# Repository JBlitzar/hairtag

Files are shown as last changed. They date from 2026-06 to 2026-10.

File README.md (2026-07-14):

# hairtag



homemade airtag that's genuinely pretty good

 - ESP32C3 chip, openhaystack firmware (more FOSS than Apple, no crazy custom die)
 - 22mm diameter board (smaller than Apple's 33, although technically the product is taller overall)
 - Probably costs less than Apple (legit like $2 per board after paying the $40 flat setup fees)
    - (but if cost was really what you were hoping for, buy an aliexpress knockoff)
 - Comparable battery life to apple! (~229 days theoretically)
    - Actually configurable depending on what temporal accuracy you need and which ma consumption figure you believe: https://www.desmos.com/calculator/mcncridlhq
 - Designed in California (just like apple lol)

 ## Why I made this project

 I thought airtags were pretty cool. A while ago I was scrolling Github and I came across [openhaystack](https://github.com/seemoo-lab/openhaystack) (btw Seemoo lab has done all sorts of cool things that I've used before, shoutout to nexmon and opendrop). 

 Anyways, I figured I could make my own. It's good experience, because you basically get all the components of a devboard, plus power budgeting, and interesting firmware. Plus, I already own 10000 devboards but I own zero airtags so this is a product that I'd actually use and want. A project that has both cool value and educational value gives you so much more motivation than one that only has the latter. 

## Schematic



## PCB



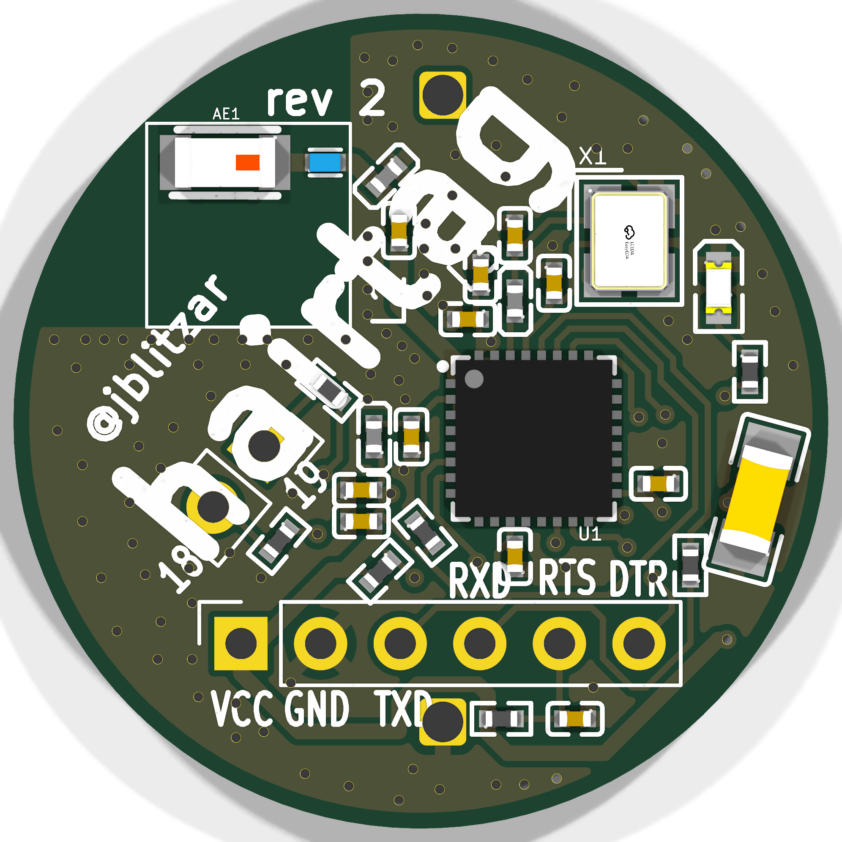
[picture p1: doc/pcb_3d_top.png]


## Wiring diagram for flashing

The standard way is a CP2102 USB-UART dongle wired straight to the flashing header (VCC, GND, TXD, RXD, EN, DTR):

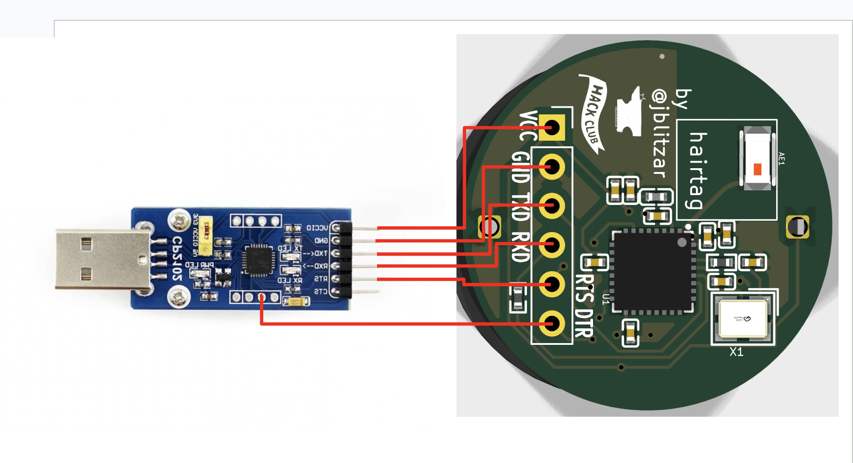
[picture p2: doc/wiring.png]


Alternatively, if you have an [Icepi Zero](https://www.crowdsupply.com/icy-electronics/icepi-zero) FPGA, you can use its onboard USB-UART bridge as the flasher. See [`software/fpga/`](software/fpga/).

## Gallery

https://github.com/user-attachments/assets/a9827342-8f9d-4dc0-8821-d6cf14613d8d

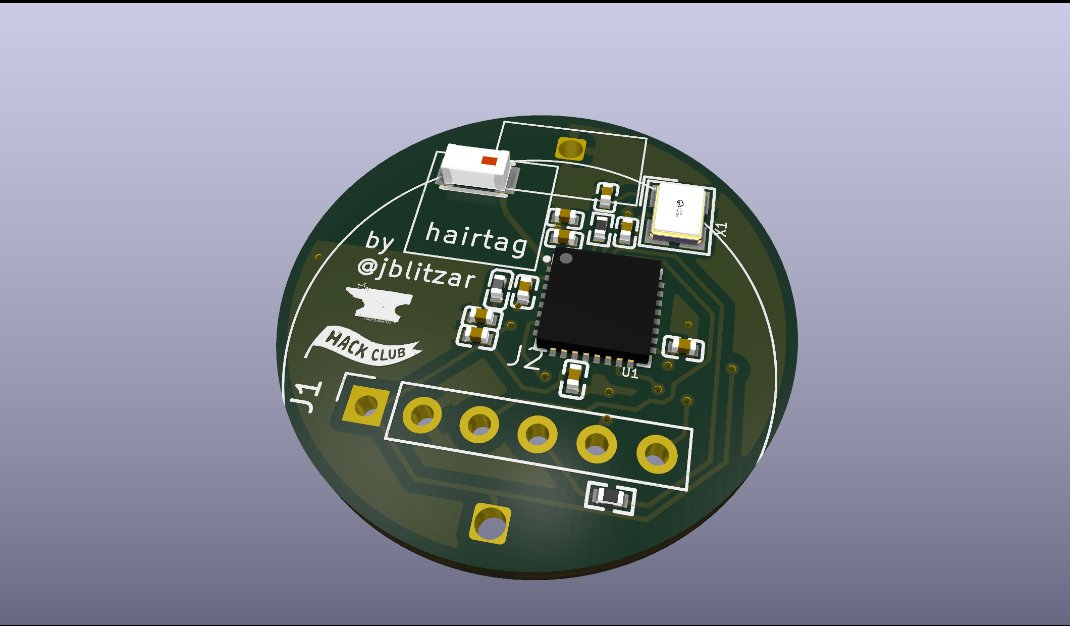
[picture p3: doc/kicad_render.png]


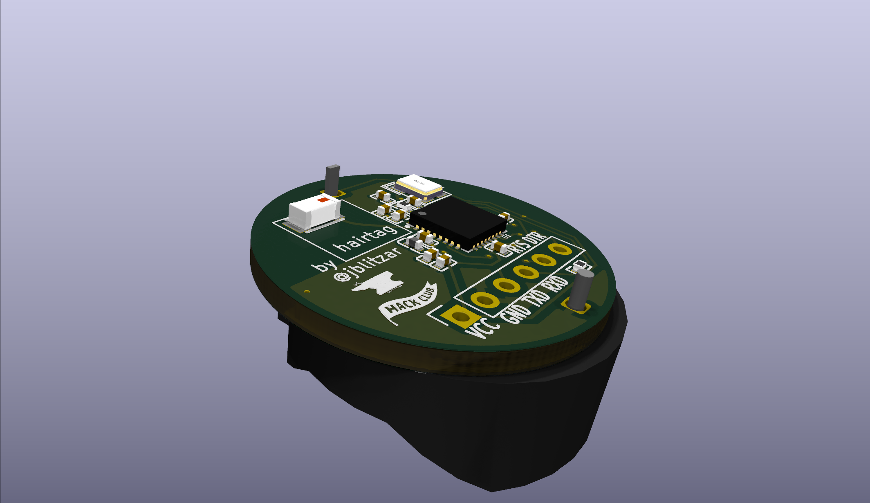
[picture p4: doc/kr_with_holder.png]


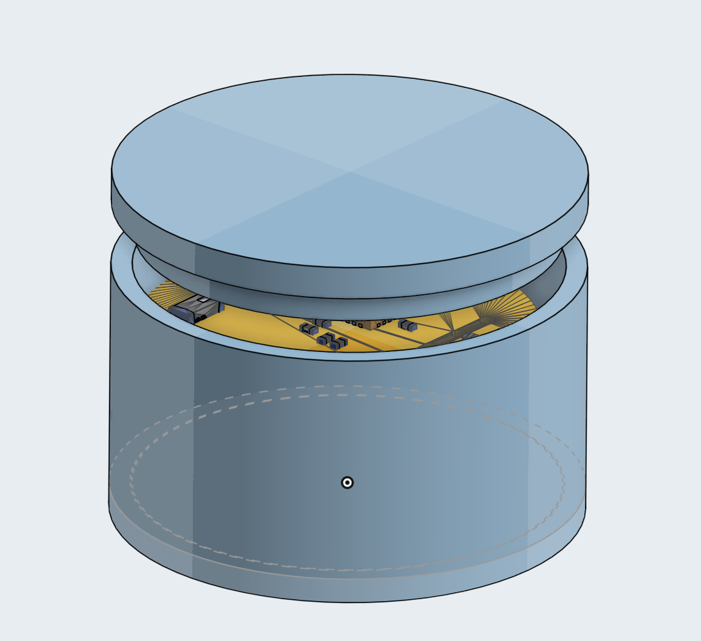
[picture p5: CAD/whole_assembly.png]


## Usage instructions

See [`software/README.md`](software/README.md). It's quite involved.

## Bom

|Item |Link |Cost |Notes |Running Total|
|---|---|-----|---|---|
|CP2102 for flashing |http://waveshare.com/cp2102-usb-uart-board-type-a.htm |4.99 |This one has a specific pinout that's useful, also waveshare's more reputable |4.99 |
|PCB + PCBA + JLC shipping|N/A |42.02|Cost for 2x pcba. I'm willing to pay $4 extra out of pocket to get the 5x PCBA |47.01 |
|CR2032 batteries |https://www.aliexpress.us/item/3256808176964698.html |0 |self-sourced, alt amazon link: https://www.amazon.com/Energizer-2032-Battery-CR2032-Lithium/dp/B0042A9UXC?th=1 |47.01 |
|battery holder |https://www.amazon.com/RuiLing-CR2032-Button-Battery-Holder/dp/B07PNK5D6H|6.69 |it's actually cheaper than what I could find on aliexpress (at least that had the footprint that I wanted and free shipping)|53.7 |
|Shipping / taxes |N/A |11 |TBD, from all the other ones not counting pcba |64.7 |
|Case (printed) |N/A |0 |self-sourced, alternatively print legion is also free |64.7 |

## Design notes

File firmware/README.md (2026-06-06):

# Firmware

This directory contains everything needed to turn an ESP32-C3 into an Apple Find My tracker and query its location from your machine.

Think of it this way: I basically got five half-broken implementations off of github, all at least two years old, tried things until it worked, and merged them together into one cursed readme here.

This was one of the hardest installation processes I've ever documented (or done), probably superseded in difficulty only to that one arm64 rabbit r1 rooting project.

This will likely only work on a mac, because apple is apple.

For the sake of reproducibility, here's what to do:

## How it works

1. `esp32c3-openhaystack/` runs on the ESP32-C3 and broadcasts BLE advertisements that Apple devices interpret as a Find My accessory.
2. `findmy/` runs on your computer, authenticates with Apple, and fetches/decrypts location reports from the Find My network.

## Prerequisites

- macOS (special apple things)
- [Docker Desktop](https://www.docker.com/products/docker-desktop/) running
- [uv](https://docs.astral.sh/uv/) package manager
- An Apple ID with SMS 2FA enabled
- The flashing setup as described in [README.md](/README.md#wiring-diagram-for-flashing)

## Anisette server

```bash
docker network create mh-network
docker run -d --restart always --name anisette -p 6969:6969 \
  --volume anisette-v3_data:/home/Alcoholic/.config/anisette-v3 \
  --network mh-network \
  dadoum/anisette-v3-server
```

Verify it's running:

```bash
curl http://localhost:6969
```

## Generate keys

See instructions in the esp32c3 README: [`esp32c3-openhaystack/README.md`](esp32c3-openhaystack/README.md)

```bash
cd esp32c3-openhaystack/
uv sync
uv run scripts/keygen.py
```

This creates a `.keys` file (e.g. `XXXXX.keys`) in the `scripts/output/` directory containing your private key, advertisement key, and hashed advertisement key. Copy the .keys file to `findmy`.

## Flash the firmware

Follow the instructions in [`esp32c3-openhaystack/README.md`](esp32c3-openhaystack/README.md). In short:

```bash
cd esp32c3-openhaystack/
# Build and flash firmware
pio run -t upload
# Write your keys to the device (copy your .keys file to scripts/input/ first)
python3 scripts/keywriter.py
```

After flashing and resetting, the device starts advertising immediately.

## Create the reports database

```bash
cd findmy/
sqlite3 reports.db 'CREATE TABLE reports (id_short TEXT, timestamp INTEGER, datePublished INTEGER, payload TEXT, id TEXT, statusCode INTEGER, PRIMARY KEY(id_short,timestamp))'
```

## Authenticate with Apple

Disclaimer: I'm not responsible if something happens to your apple account. Prefer an alt account.

My personal advice is that it's probably fine though.

```bash
cd findmy/
uv run request_reports.py --regen
```

You'll be prompted for your Apple ID, password, and a 2FA code.

Now, you won't actually get a 2fa code texted to you. For that, go to icloud.com, sign in, it will give send an approval code to your phone. But don't use that either. You click, "can't use this device" or whatever, then select the option to send an *SMS* code via text. Then paste that sms code (not the initial approval code) into the terminal (not icloud.com)

On success, the script saves `auth.json` in the `findmy/` directory. Subsequent runs reuse it without prompting.

## Query locations

```bash
cd findmy/
./locate.sh
```

Output looks like:

```
200: 8 reports received.
8 reports used.

{'lat': 33.6104, 'lon': -153.3900, 'conf': 1, 'status': 0, 'timestamp': 1749234567, 'isodatetime': '2026-06-06T14:42:47', 'key': 'XXXXX', 'goog': 'https://maps.google.com/maps?q=33.6104,-153.3900'}
found:   ['XXXXX']
missing: []
```

The `goog` URL opens the location in Google Maps.

a TODO for the future is to make this a nice TUI. 

### Options

| Flag | Default | Description |
|---|---|---|
| `--hours` | 24 | Look back this many hours for reports |
| `--regen` | off | Force re-authentication (needed when token expires) |
| `--prefix` | (none) | Only query `.keys` files starting with this prefix |
| `--trusteddevice` | off | Use trusted device 2FA instead of SMS |

## Auth token expiry

idk, sometimes it expires.

```bash
uv run request_reports.py --regen
```

The anisette Docker container must be running for this to work.

## On apple IDs

You could make a burner apple id if you want I guess, it's kind of a pain though, what with the android apple music bypass and whatnot.

## Licensing

I did not write this myself. I copied these two repositories, patched them so that they worked, and put them together.

Thank you, @biemster, @timbeh, and of course seemoo lab. 

https://github.com/biemster/FindMy

https://github.com/timbeh/esp32c3-openhaystack

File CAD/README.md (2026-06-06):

## Cad

Onshape link: https://cad.onshape.com/documents/0e94dcea26cc064076fa7957/w/f8a446f4ff724744298d30b3/e/f3de4cc3b830680613227711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

Exported STEPs also available in this directory.

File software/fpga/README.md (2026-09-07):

# Icepi Zero FPGA flasher

This is how I'm going to personally flash since I want to avoid spending 16 dollars. 

You only need this if you happen to have an Icepi Zero lying around. For
everyone else, the CP2102 dongle in the main
[wiring diagram](/README.md#wiring-diagram-for-flashing) is simpler.

## How it works

[`top.sv`](top.sv) is a pure combinational pass-through. esptool talks to the
Icepi's onboard FTDI exactly as it would to a CP2102; the FPGA just forwards
the data and modem-control lines (RTS->EN, DTR->boot) to four GPIOs:

| FTDI signal | FPGA pass-through | Hairtag pin |
|---|---|---|
| TXD (`usb_rx`) | `flash_txd` | TXD (ESP U0RXD) |
| RXD (`usb_tx`) | `flash_rxd` | RXD (ESP U0TXD) |
| RTS# (`usb_rtsn`)| `flash_en`  | EN (CHIP_EN) |
| DTR# (`usb_dtrn`)| `flash_dtr` | DTR (GPIO9 boot)|

## Wiring

The four signal GPIOs sit on the odd-numbered outer row, so VCC/GND/signals
are all reachable along one side of the 40-pin header:

| Hairtag pin | Icepi 40-pin header | ECP5 site |
|---|---|---|
| VCC | pin 1 (3V3) | — (rail) |
| GND | pin 9 (GND) | — (rail) |
| TXD | pin 3  | T2 |
| RXD | pin 5  | R2 |
| EN  | pin 7  | R1 |
| DTR | pin 11 | R3 |



## Build and load

Requires the open-source ECP5 toolchain (`yosys`, `nextpnr-ecp5`, `ecppack`,
`openFPGALoader`).

```bash
make debug    # load to SRAM (lost on power cycle) - good for flashing sessions
make install  # write to flash (persists)
make clean
```

Once the bitstream is loaded, flash the hairtag the normal way (`pio run -t
upload`, `keywriter.py`, etc.) pointing esptool at the Icepi's serial port.

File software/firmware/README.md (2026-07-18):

# README copied from original repo. Not all this info is relevant. Also at this point the code has been heavily modified. 

See https://github.com/timbeh/esp32c3-openhaystack .

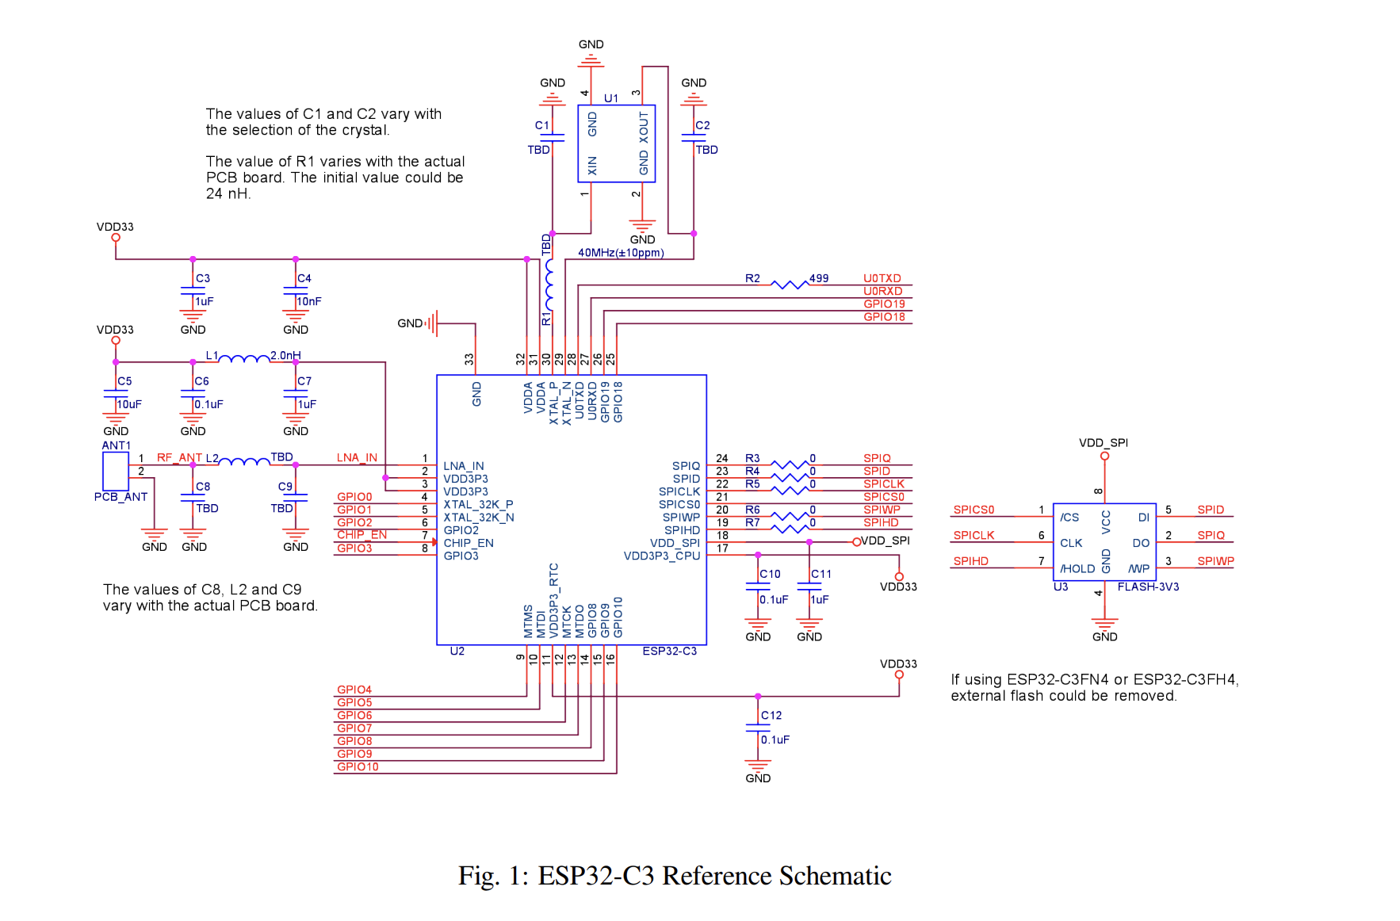
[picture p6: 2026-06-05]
doc/esp_ref_schematic.png

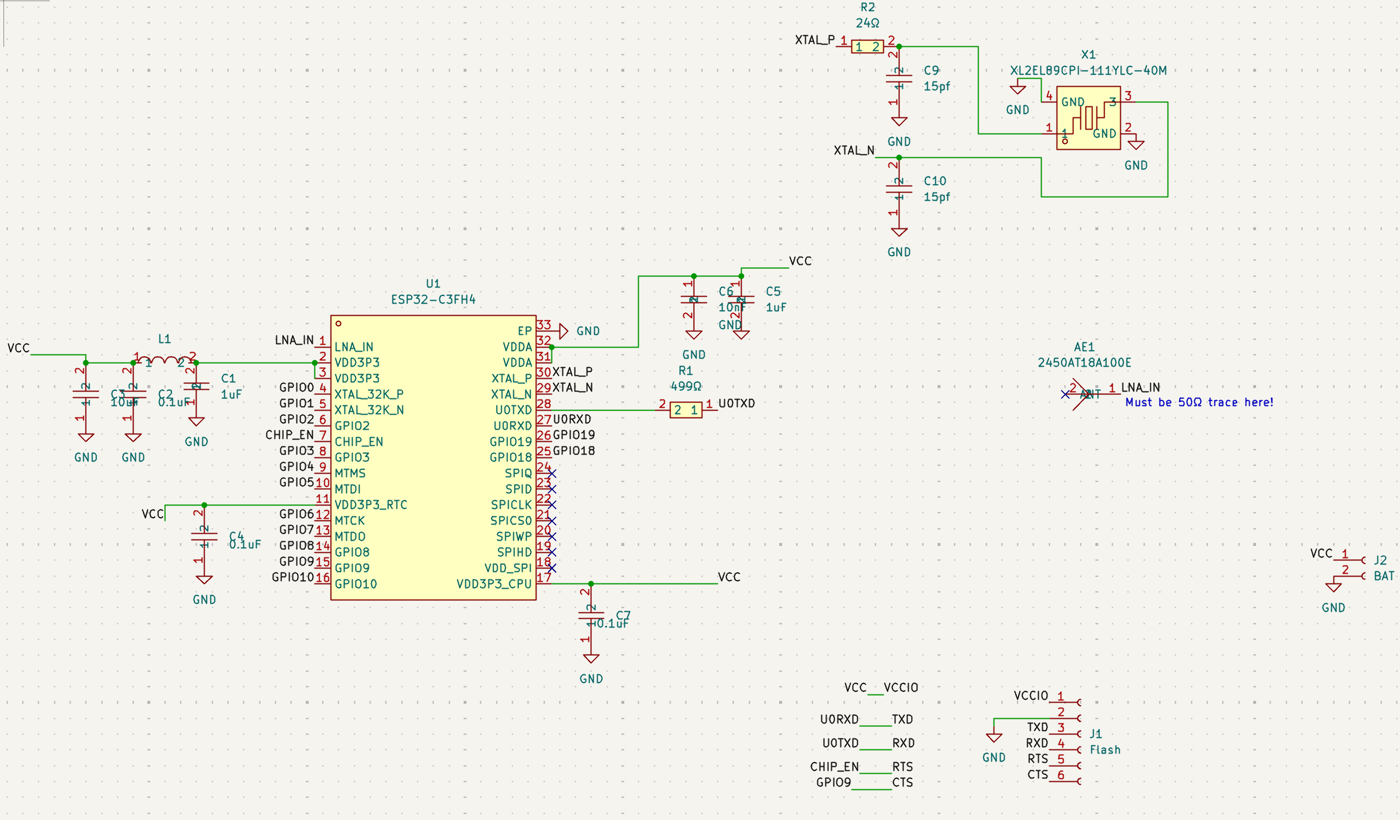
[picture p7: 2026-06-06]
doc/schematic.png

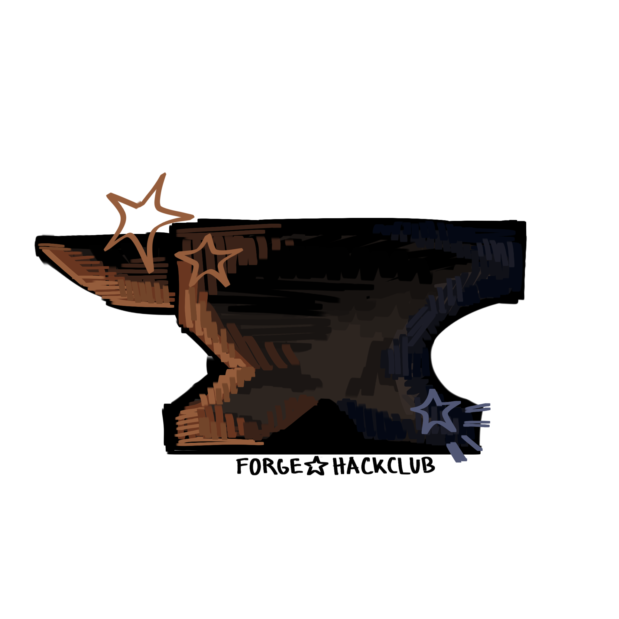
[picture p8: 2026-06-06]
doc/forge.png

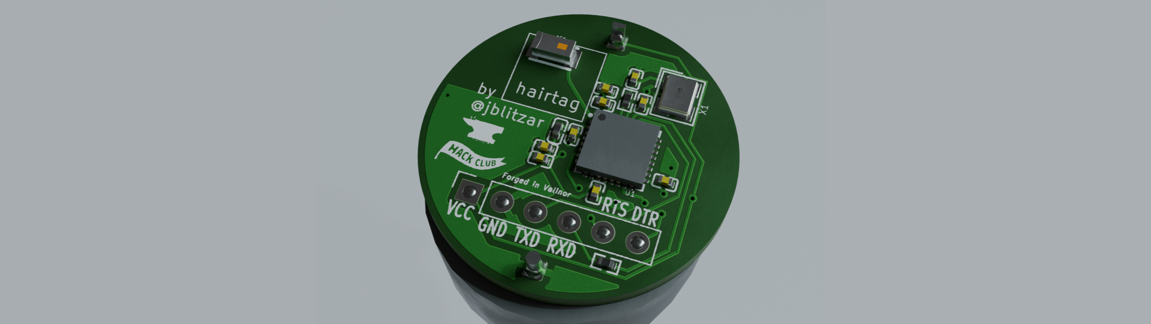
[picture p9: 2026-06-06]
CAD/render/br1_wide.png

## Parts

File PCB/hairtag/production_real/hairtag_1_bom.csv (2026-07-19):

Designator | Footprint | Quantity | Value | LCSC Part #
AE1 | ANT-SMD_L3.2-W1.6 | 1 | 2450AT18A100E | C89334
C1, C5, C8 | C0402 | 3 | 1uF | C52923
C10, C9 | C0402 | 2 | 15pf | C1548
C11 | C1206 | 1 | 100uF | C15008
C12 | C0402 | 1 | 1pF | C1550
C2, C4, C7 | C0402 | 3 | 0.1uF | C1525
C3 | C0402 | 1 | 10uF | C15525
C6 | C0402 | 1 | 10nF | C15195
L1 | L0402 | 1 | 2nH | C76769
L2 | L0402 | 1 | 15nH | C27143
L3 | L0402 | 1 | 2.7nH | C27123
L4 | IND-SMD_L1.0-W0.5-2 | 1 | 3.9nH | C98062
LED1 | LED0603-RD | 1 | FC-1608YXK-585F08 | C2286
R1 | R0402 | 1 | 499Ω | C2960788
R2, R7 | R0402 | 2 | 22 | C25092
R3 | R0402 | 1 | 0402WGF3300TCE | C25104
R4, R5, R6 | R0402 | 3 | 10k | C25744
U1 | QFN-32_L5.0-W5.0-P0.50-TL-EP3.7 | 1 | ESP32-C3FH4 | C2858491
X1 | CRYSTAL-SMD_4P-L3.2-W2.5-BL | 1 | XL2EL89CPI-111YLC-40M | C5444549

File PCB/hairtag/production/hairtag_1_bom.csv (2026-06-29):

Designator | Footprint | Quantity | Value | LCSC Part #
AE1 | ANT-SMD_L3.2-W1.6 | 1 | 2450AT18A100E | C89334
C1, C5 | C0402 | 2 | 1uF | C52923
C10, C9 | C0402 | 2 | 15pf | C1548
C11 | C1206 | 1 | 100uF | C15008
C2, C4, C7 | C0402 | 3 | 0.1uF | C1525
C3 | C0402 | 1 | 10uF | C15525
C6 | C0402 | 1 | 10nF | C15195
C8 | C0402 | 1 | 1uF | C29266
J1 | PinSocket_1x06_P2.54mm_Vertical | 1 | Flash
J2 | Untitled | 1 | BAT
L1 | L0402 | 1 | 2nF | C76769
L2 | L0402 | 1 | 15nH | C76769
LED1 | LED0603-RD | 1 | FC-1608YXK-585F08 | C89811
R1 | R0402 | 1 | 499Ω | C2960788
R2, R7 | R0402 | 2 | 22 | C105872
R3 | R0402 | 1 | 0402WGF3300TCE | C105872
R4, R5, R6 | R0402 | 3 | 10k | C105872
U1 | QFN-32_L5.0-W5.0-P0.50-TL-EP3.7 | 1 | ESP32-C3FH4 | C2858491
USB1 | PinSocket_1x02_P2.54mm_Vertical | 1 | USB
X1 | CRYSTAL-SMD_4P-L3.2-W2.5-BL | 1 | XL2EL89CPI-111YLC-40M | C5444549

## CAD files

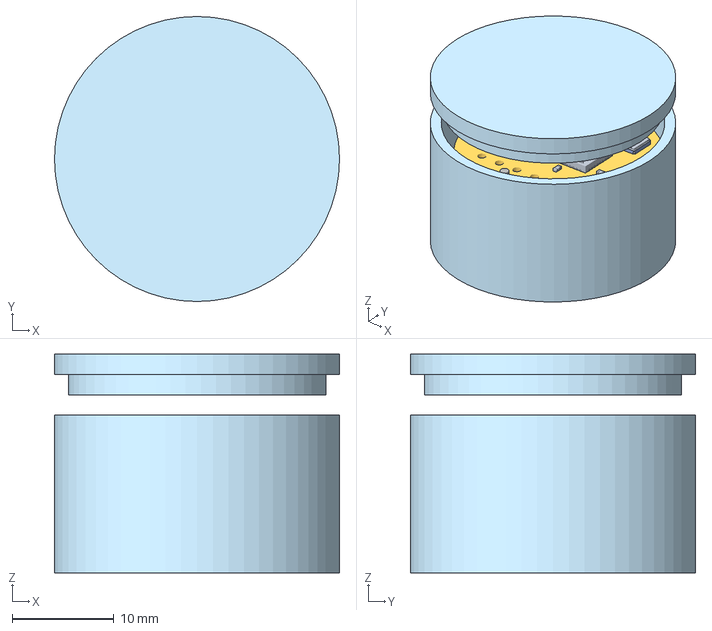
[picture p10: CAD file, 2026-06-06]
CAD/hairtag_whole_assembly.step
28.0 x 28.0 x 21.5 mm

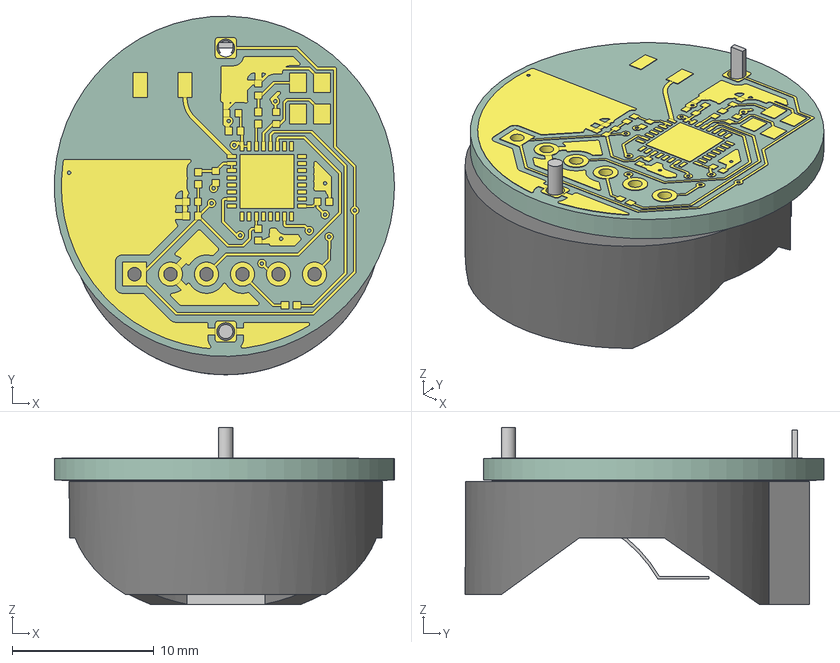
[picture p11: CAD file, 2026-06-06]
doc/hairtag_pcb_merged.step
24.0 x 25.3 x 12.5 mm
ť x 3
hairtag_copper
hairtag_PCB

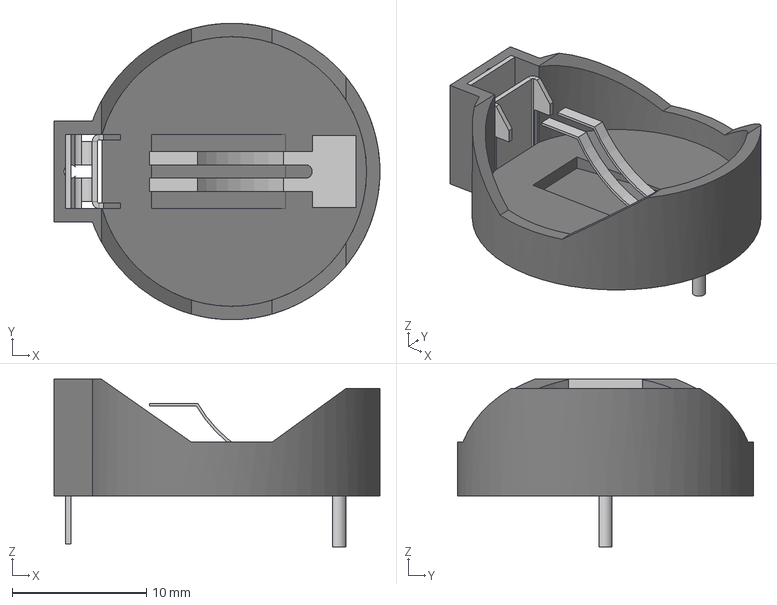
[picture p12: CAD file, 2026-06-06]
PCB/hairtag/battery_holder.stp
24.3 x 22.1 x 12.5 mm

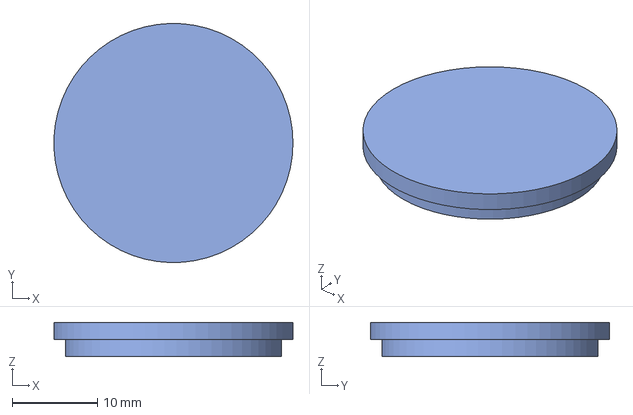
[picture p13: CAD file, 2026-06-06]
CAD/case_top.step
28.0 x 28.0 x 4.00 mm

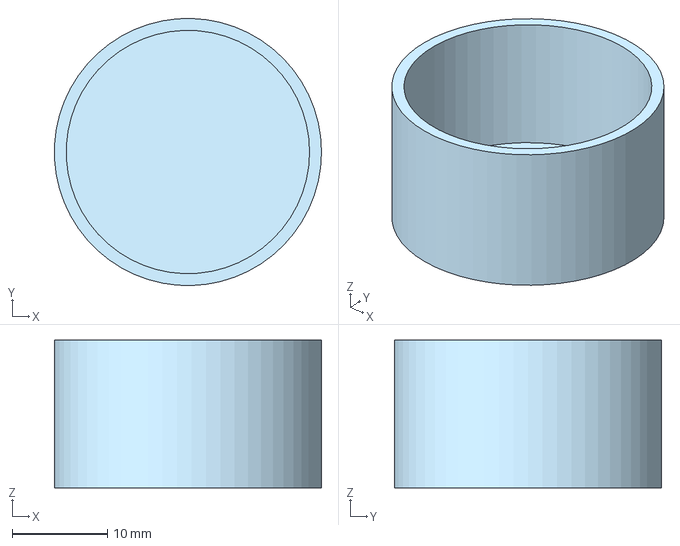
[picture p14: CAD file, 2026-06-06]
CAD/case_bottom.step
28.0 x 28.0 x 15.5 mm

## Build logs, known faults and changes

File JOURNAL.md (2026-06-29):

---
title: "hairtag"
author: "jblitzar"
description: "homemade airtag that's genuinely pretty good"
created_at: "2026-06-04"
---

# 6/4/2026 9 AM - Research and project idea

_Time spent: 1.5h_

Basically did some research and thinking about this project. I think it has the potential to be really cool. I sent my musings in slack to ask for feedback, but here's how it's feeling so far:

I think it'd be cool to make my own airtags. There exists openhaystack firmware to connect to apple's mesh, so this is feasible at least in theory, plus there already exist third party airtags so others have done it at least
In terms of complexity, I'd imagine it's at or above a devboard.
One hard part is going to be power mangement

In terms of capable chips, I see two options: the esp32 and the nrf. Both have openhaystack ports.

esps have ble soc, and I think the c3 is pretty stripped down and optimized. It draws maybe 150 ua, so about six months on an AAA battery, pretty good

There's also the nrf, which is more "professional grade" I guess. It has a harder toolchain, but draws much less current. Even on a tiny cr2032 coin battery, it'd last a really long time. I'm leaning towards the c3 though.

With regards to that, I also have the option of using the raw qfn chip or using the package. Both fit within spatial budget.

What I'm leaning towards now is esp32c3 qfn, off the shelf external antenna, AAA battery. It's not quite the professional form factor of the coin cell x nrf, but honestly it has some charm to it. qfn feels like just the right amount of challenge, and also I want pcba :wesh:



Alright, locking things in:

- MCU: esp32c3 qfn: https://www.lcsc.com/product-detail/C2858491.html
- Antenna: Molex 2450AT18A100E (datasheet: https://www.lcsc.com/datasheet/C89334.pdf)
- Power: battery tbd (probably AAA)
- Firmware: Openhaystack for esp32
- Flashing: expose tx,rx,gnd,boot,en plus CP2102

# 6/4/2026 4 PM - Schematic and Placement

_Time Spent: 3h_

Found a great datasheet on the esp32, https://docs.espressif.com/projects/esp-hardware-design-guidelines/en/latest/esp32c3/esp-hardware-design-guidelines-en-master-esp32c3.pdf

Absolute gold mine; It has a reference design.

Anyways, useful stuff for the future:

1uf: C52923
inductor: C76769 2nH
100nf: C1525
10uf: C15525
10nf: C15195
499Ω: C2960788
crystal: C5444549 (specify 10pf) (datasheet: https://www.lcsc.com/datasheet/C5444549.pdf)
15pf: C1548
24Ω: C270625

Here's what it looks like!



And the placement: 



I also researched firmware, I found this lovely implementation at https://github.com/timbeh/esp32c3-openhaystack/tree/main .
Now, if it advertises for just 20ms and then deep sleeps for the rest of the ten seconds, that consumes  = 0.03996 mA, so on a 220 mAh battery, that's 229 days of life!! This is pretty great, so we don't even need to worry about optimizing life. No nrf regrets.

So the coin cell is back on the table. So I just slightly redesigned the form factor. Honestly, this is pretty good to almost start routing.



Actually, update: I was able to fully fit the whole thing inside a 22mm circle.


Things to consider with routing:
 - Silly stuff with the impedance of the antenna (most annoying)
  - Double check this with the datasheet.
  - Also keep out zone
 - Caps, antenna, crystal should all be via-free, the rest is fair game (signal, ground, power)
  - What this likely means is that I should route these first. 

# 6/4/2026 9 PM - First pass on routing

_Time Spent: 0.5h_

Reasonably fast routing thanks to my immaculate placement lol, just a bit of nudging around.

DRC passes! Just had to connect all the gnd planes, no other issues

Impedence calculators said that I would need a 3mm (!!) thick trace for my ble, but the pitch on the qfn package is literally 0.5mm. According to the internet, at my type of application, honestly, impedence matching is not allat. It'll be a negligible difference, I'm not trying to squeeze every last db out of this, it just needs to transmit to the nearest phone. So I guess I'll be getting 109Ω impedance instead of the reccommended 50Ω.

Internet says: "A safe rule of thumb in digital and low-frequency design is that if your trace or wire is less than 1/10 of the signal's wavelength, transmission line effects don't matter. Reflections won't have time to interfere with the original signal." My wire is 6mm and ble is 2.4ghz, so that's like 120mm. So I am fine.

Picture: 



TODOs eventually:
 - add silkscreen art
 - add the rest of the docs to make it shipped. This means:
  - BOM fully figured out (this has items not in pcba like the batteries!)
  - nice readme
  - nice case
  - et al.

We'll see how pricing comes out.

# 6/5/2026 3 PM - Silkscreen, BOM, docs

_Time Spent: 2.5h_

BOM optimization: swapped 4 extended LCSC parts for basic equivalents to cut PCBA costs.

https://basicp.art/ is such a gem of a resource

- C29266 -> C52923
- C60474 -> C1525
- C315248 -> C15525
- C86285 -> C1548

I also fleshed out the sourcing for the rest of the parts. I could spend some more time looking at alternatives, but it's about as cheap as it's going to get. I have as many Basic parts as possible, I'll probably pay for battery holders out of pocket, and a cheaper CP2102 will save me only like $5.

So while I was looking at my battery holders, I realized that I don't actually have to solder any bodge wires, and that there exists one with a very slick PCB integration. So I designed up a footprint and put it in. 


See, those pins can actually go into tht pads. These folks did it:



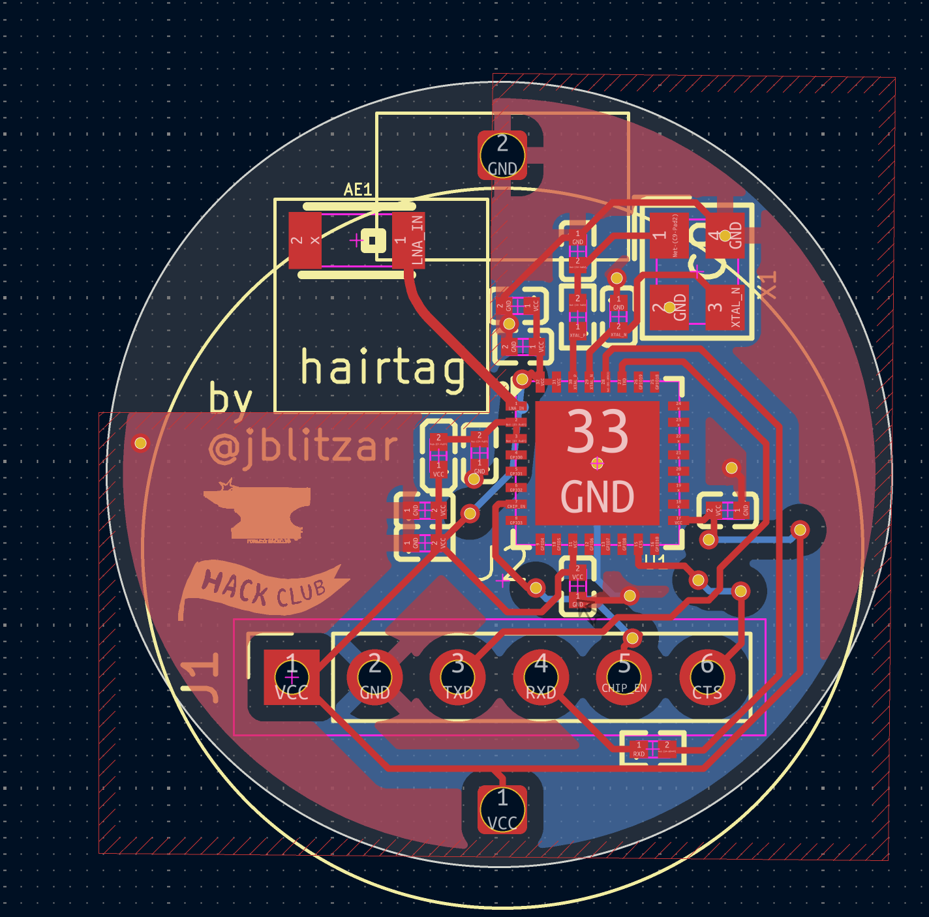
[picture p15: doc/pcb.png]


Alright, time to design a case.

I think a simple press fit will do. This is a ~25.5mm diameter circle, which accounts for the weird overlapping footprints. It'll be a weird fit, but it'll look cool on the outside

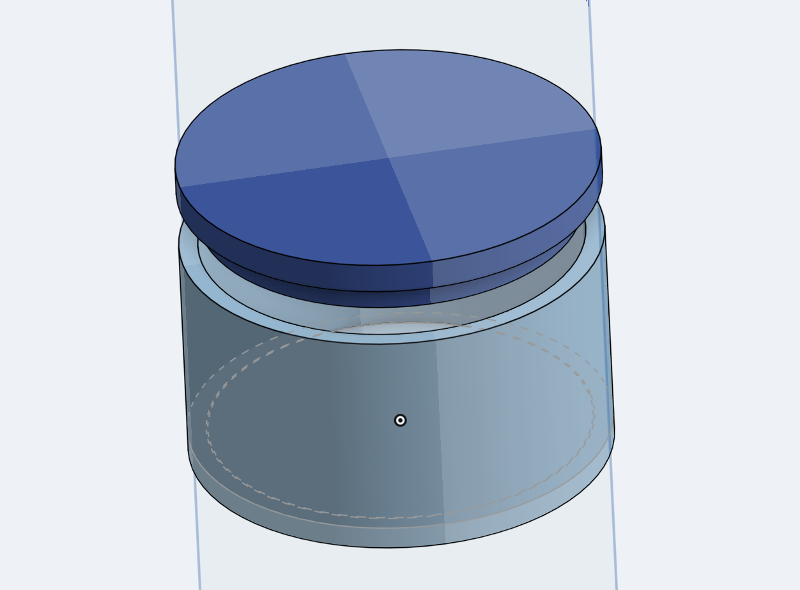
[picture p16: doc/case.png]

Next up, I wrote the README. For next session, I'll want to make a nicer render in blender, clean up the traces until they're *perfect*, and make sure that I all the proper documentation sorted here. (seems like I'll need a step file with my whole assembly)

# 6/6/2026 8 AM - README, Flashing pinout

_Time Spent: 2h_

*not counting time spent waiting for blender renders to render*

I was looking to bom optimize the flasher, but in the end, I need all the pins I'll use, because I need the RTS and DTR pins to autoboot. This is quite nice for qol. It'll be a sus bodge wire though.

Made the wiring diagram, made the composite PCB + case CAD and exported it into `CAD/`.

Next up, blender render!

Anyways, check the images in `doc/`.

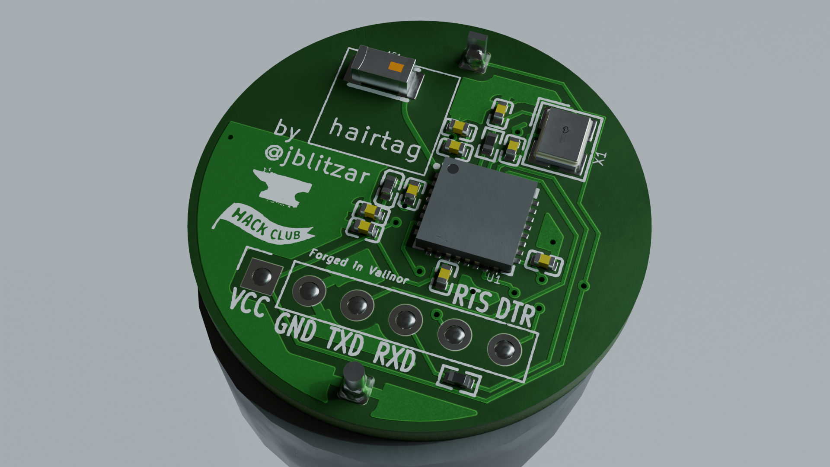
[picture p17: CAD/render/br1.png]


# 6/6/2026 1 PM - Fought demons to get firmware working

_Time Spent: 1.5h_

> at least.

**Hackatime project name**: `hairtag`, same as the repo

Doing this on a plain esp devboard because ofc parts have not arrived yet, should be the same I just edited platformio.

Basically it's everything in `firmware/`. Yeah, there were a lot of issues. I think I have tried five or six different openhaystack implementations, namely

- https://github.com/seemoo-lab/openhaystack (bad because requires sketchy legacy apple mail plugin that no longer works)
- https://github.com/timbeh/esp32c3-openhaystack (good, am using)
- https://github.com/dchristl/macless-haystack (Spent a long time on this one, auth doesnt work for whatever reason, cors errors on frontend)
- https://github.com/biemster/FindMy (Auth actually works, just a tui no frontend, tried using this auth with the macless frontend, didn't work)

My stack right now is `esp32c3-openhaystack` firmware (with the `fix-hint-byte` patch) and a patched FindMy.py that doesn't throw errors lol.
  - Update: findmy.py also had some logic bugs that I also patched regarding querying multiple keys

Anyways, I got real reports!! So ts actually works. I was so happy when I saw those jsons in stdout.

Let me expand on the journey a bit:
I spent way too long on macless-haystack, but got stuck on 2fa codes. Even the fix from the pull request that was never merged (https://github.com/dchristl/macless-haystack/pull/226) didn't work. It claims to ask for them but the codes never come to your phone.

Findmy.py's auth works but you can't use it with macless haystack because you can't reuse auths between anisette clients. 

I also had silly cors issues, which I should have ditched earlier.

Eventually gave up on the fancy frontend and just used biemster/FindMy directly. And it worked decently, still had to do the workaround for the 2fa codes like I described (sign in somewhere else, request a 2fa code, say can't access my device and need sms code, it intercepts that.)

Here it is working!!!



I made a collage when I was just starting out, so I'll make a collage here, as I'm about to submit.



# 6/28/2026 6 PM - Silkscreen rework and add LED

_Time Spent: 0.3h_
I mean, what it says. I added a yellow LED to gpio10 for debugging when firmware bring-up, and I changed the decorative silkscreen. Here's a picture of what it's looking like:



For tomorrow, I'll re-check the flashing pins, re-check that I don't need a special transistor network, and then order the boards! And then work on the fpga flasher, which will be fun I guess.

# 6/29/2026 7 AM - Final Tweaks and Ordering the Boards

_Time Spent: 1.5h_

Soo I figured I would sleep on ordering until the next day, and it was a good idea. Turns out I was missing a bunch of strapping pins etc that needed to be pulled one way or another.

Just the reference schematic doesn't tell the whole story. I found the schematic checklist though.

https://docs.espressif.com/projects/esp-hardware-design-guidelines/en/latest/esp32c3/schematic-checklist.html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

It also umm turns out that the part labelled "R1" in the reference schematic is actually an INDUCTOR, not a resistor. So I had to change that 😭.

So I...
 - added a 10k pull-up to gpio8 and gpio2
 - added a 1uf cap on vdd_spi to gnd
 - added a 100uf bulk cap on vcc to mitigate brownouts on ble spikes
  - This was a pain to place and route, the only jlc basic part package is 1206, which is a lot of real estate on the 22mm circular board! I ended up getting a really interesting placement. 90 degrees didn't work but 85 degrees did, so I went with that ☠️
 - added ground stitching vias around the antenna keepout
 - added routing and a connector for the USB flashing pins as a backup? TBD if that's easier or harder than my current method, but its nice to have options and escape routes. 
 - Made VCC lines thicker (0.5mm)
 - cleaned up traces and silkscreens overall. No DRC errors. I do have a few tilted components now, but I was able to use the back for some routing.

 Here's what it looks like now overall I guess

 

I then went on to ordering. Had to edit some stuff in the BOM for it to work (some parts were out of stock), and two components were rotated incorrectly, but otherwise it was good. See PCB/hairtag/production_real/ .



And the JLC image:



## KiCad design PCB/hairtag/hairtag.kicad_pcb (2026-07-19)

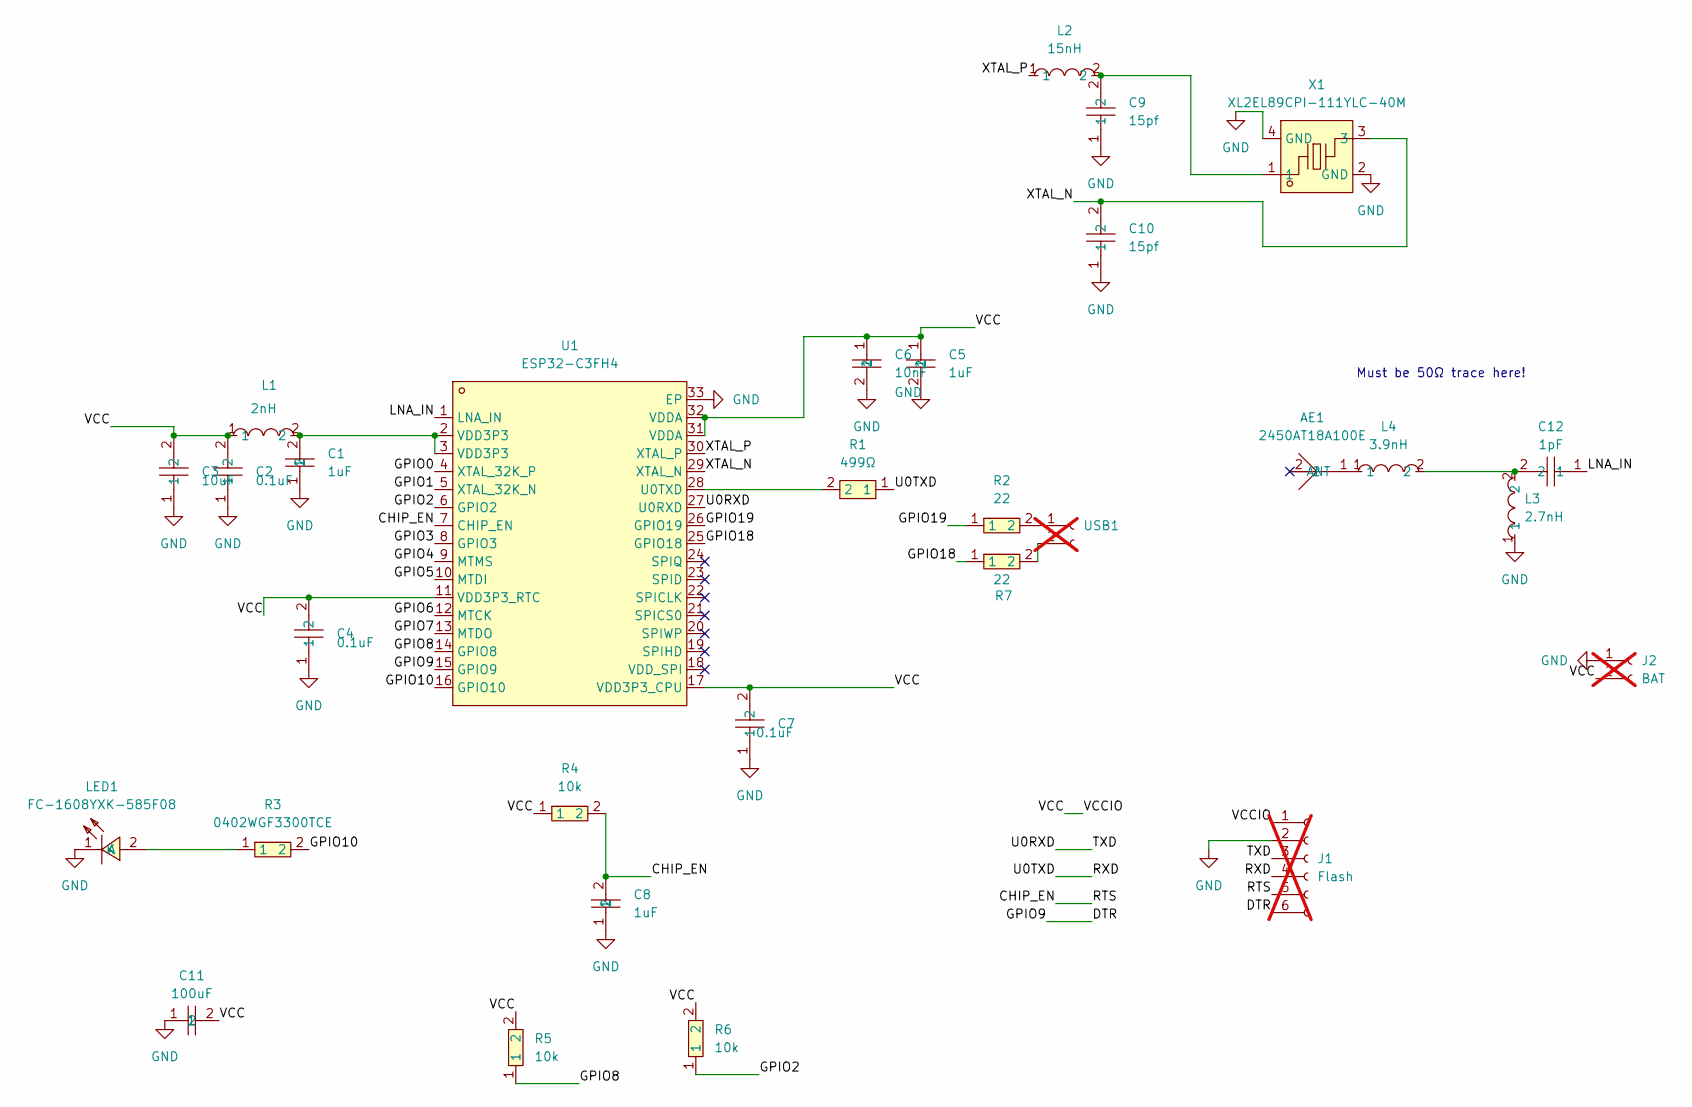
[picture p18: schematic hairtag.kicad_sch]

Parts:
AE1: 2450AT18A100E; ANT-SMD_L3.2-W1.6; MPN 2450AT18A100E; LCSC Part C89334
C1, C5, C8: 1uF; C0402; MPN CL05A105KA5NQNC; LCSC Part C52923
C2, C4, C7: 0.1uF; C0402; MPN CL05B104KO5NNNC; LCSC Part C1525
C3: 10uF; C0402; MPN CL05A106MQ5NUNC; LCSC Part C15525
C6: 10nF; C0402; MPN CL05B103KB5NNNC; LCSC Part C15195
C9, C10: 15pf; C0402; MPN 0402CG150J500NT; LCSC Part C1548
C11: 100uF; C1206; MPN CL31A107MQHNNNE; LCSC Part C15008
C12: 1pF; C0402; MPN 0402CG1R0C500NT; LCSC Part C1550
J1: Flash; PinSocket_1x06_P2.54mm_Vertical; not fitted
J2: BAT; Untitled; not fitted
L1: 2nH; L0402; MPN MLG1005S2N0BT000; LCSC Part C76769
L2: 15nH; L0402; MPN SDCL1005C15NJTDF; LCSC Part C27143
L3: 2.7nH; L0402; MPN SDCL1005C2N7STDF; LCSC Part C27123
L4: 3.9nH; IND-SMD_L1.0-W0.5-2; MPN LQW15AN3N9B00D; LCSC Part C98062
LED1: FC-1608YXK-585F08; LED0603-RD; MPN KT-0603R; LCSC Part C2286
R1: 499Ω; R0402; MPN FRC0402F4990TS; LCSC Part C2960788
R2, R7: 22; R0402; MPN 0402WGF220JTCE; LCSC Part C25092
R3: 0402WGF3300TCE; R0402; MPN 0402WGF3300TCE; LCSC Part C25104
R4, R5, R6: 10k; R0402; MPN 0402WGF1002TCE; LCSC Part C25744
U1: ESP32-C3FH4; QFN-32_L5.0-W5.0-P0.50-TL-EP3.7; MPN ESP32-C3FH4; LCSC Part C2858491
USB1: USB; PinSocket_1x02_P2.54mm_Vertical; not fitted
X1: XL2EL89CPI-111YLC-40M; CRYSTAL-SMD_4P-L3.2-W2.5-BL; MPN XL2EL89CPI-111YLC-40M; LCSC Part C5444549

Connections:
/CHIP_EN: C8.2, J1.5, R4.2, U1.7 (CHIP_EN)
/DTR: J1.6, U1.15 (GPIO9)
/GPIO0: U1.4 (XTAL_32K_P)
/GPIO1: U1.5 (XTAL_32K_N)
/GPIO2: R6.1, U1.6 (GPIO2)
/GPIO3: U1.8 (GPIO3)
/GPIO4: U1.9 (MTMS)
/GPIO5: U1.10 (MTDI)
/GPIO6: U1.12 (MTCK)
/GPIO7: U1.13 (MTDO)
/GPIO8: R5.1, U1.14 (GPIO8)
/GPIO10: R3.2, U1.16 (GPIO10)
/GPIO18: R7.1, U1.25 (GPIO18)
/GPIO19: R2.1, U1.26 (GPIO19)
/LNA_IN: C12.1, U1.1 (LNA_IN)
/RXD: J1.4, R1.1
/TXD: J1.3, U1.27 (U0RXD)
/VCC: C2.2, C3.2, C4.2, C5.1, C6.1, C7.2, C11.2, J1.1, J2.2, L1.1, R4.1, R5.2, R6.2, U1.11 (VDD3P3_RTC), U1.17 (VDD3P3_CPU), U1.31 (VDDA), U1.32 (VDDA)
/XTAL_N: C10.2, U1.29 (XTAL_N), X1.3
/XTAL_P: L2.1, U1.30 (XTAL_P)
GND: C1.1, C2.1, C3.1, C4.1, C5.2, C6.2, C7.1, C8.1, C9.1, C10.1, C11.1, J1.2, J2.1, L3.1, LED1.1 (K), U1.33 (EP), X1.2 (GND), X1.4 (GND)
unnamed: AE1.1 (ANT_1), L4.1
unnamed: C1.2, L1.2, U1.2 (VDD3P3), U1.3 (VDD3P3)
unnamed: C9.2, L2.2, X1.1
unnamed: C12.2, L3.2, L4.2
unnamed: LED1.2 (A), R3.1
unnamed: R1.2, U1.28 (U0TXD)
unnamed: R2.2, USB1.1
unnamed: R7.2, USB1.2

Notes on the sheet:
Must be 50Ω trace here!

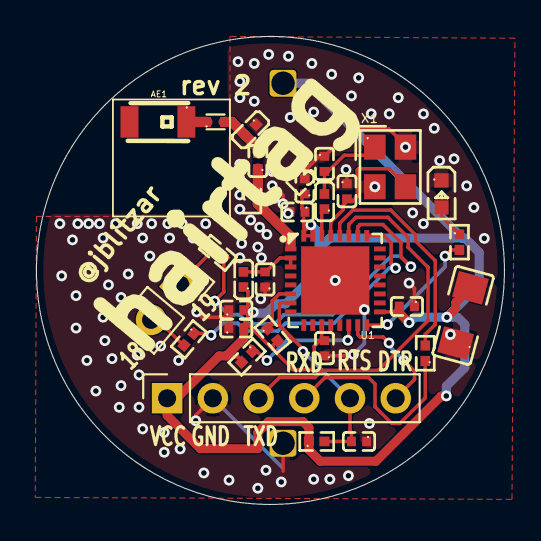
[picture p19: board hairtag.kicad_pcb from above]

Board: 2 copper layers, 26.0 x 26.0 mm, 30 parts (1 on the bottom side), 22 nets.

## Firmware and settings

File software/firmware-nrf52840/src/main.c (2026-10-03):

#include <zephyr/kernel.h>
#include <zephyr/devicetree.h>
#include <zephyr/sys/printk.h>
#include <zephyr/bluetooth/bluetooth.h>
#include <zephyr/bluetooth/hci.h>
#include <zephyr/bluetooth/addr.h>
#include <zephyr/drivers/adc.h>
#include <zephyr/drivers/gpio.h>
#include <zephyr/pm/device.h>
#include <zephyr/storage/flash_map.h>
#include <zephyr/kvss/nvs.h>
#include <string.h>

#include "keys.h"

#ifndef KEY_ROTATION_INTERVAL_MS
#define KEY_ROTATION_INTERVAL_MS (3 * 60 * 60 * 1000)
#endif

#define CHUNK_MS (5 * 60 * 1000)
#define CHUNKS_PER_ROT (KEY_ROTATION_INTERVAL_MS / CHUNK_MS)
#define NVS_ID_PROGRESS 3
#define PROGRESS_MAX (KEY_COUNT * CHUNKS_PER_ROT)
#define NVS_SECTOR_SIZE 4096

BUILD_ASSERT(PARTITION_SIZE(storage_partition) % NVS_SECTOR_SIZE == 0,
             "storage_partition must be a whole number of NVS sectors");
BUILD_ASSERT(PROGRESS_MAX <= UINT16_MAX, "progress counter must fit in uint16_t");

static struct nvs_fs nvs = {
    .flash_device = PARTITION_DEVICE(storage_partition),
    .offset = PARTITION_OFFSET(storage_partition),
    .sector_size = NVS_SECTOR_SIZE,
    .sector_count = PARTITION_SIZE(storage_partition) / NVS_SECTOR_SIZE,
};

static uint8_t mfg_data[29];

static struct bt_data ad[] = {
    BT_DATA(BT_DATA_MANUFACTURER_DATA, mfg_data, sizeof(mfg_data)),
};

/* status byte: bits 7-5 + 3-1 = battery code (0-63, 2.5V-4.2V),
   bit 4 forced low (AirTag/AirPods MSNs have it set and trigger UT alerts) */
#define STATUS_IDX 4
#define STATUS_FIXED 0x0c
#define BATT_MV_MIN 2500
#define BATT_MV_MAX 4200

/* XIAO battery divider: VBAT -> 1M -> P0.31/AIN7 -> 510k -> P0.14,
   enabled by driving P0.14 low, disconnected otherwise so the divider
   does not sink ~2.6 uA continuously */
#define DIVIDER_NUM 1510
#define DIVIDER_DEN 510
#define VBAT_ENABLE_PIN 14

static const struct device *adc_dev = DEVICE_DT_GET(DT_NODELABEL(adc));
static const struct device *gpio0_dev = DEVICE_DT_GET(DT_NODELABEL(gpio0));
static const struct device *ext_flash_dev = DEVICE_DT_GET(DT_NODELABEL(p25q16h));
static const struct adc_dt_spec vbat_channel =
    ADC_DT_SPEC_GET(DT_PATH(zephyr_user));

static int battery_mv(void)
{
    int16_t raw;
    int32_t mv;
    int err;
    struct adc_sequence seq = {
        .channels = BIT(vbat_channel.channel_id),
        .buffer = &raw,
        .buffer_size = sizeof(raw),
        .resolution = 12,
    };

    gpio_pin_configure(gpio0_dev, VBAT_ENABLE_PIN,
                       GPIO_OUTPUT | GPIO_OUTPUT_INIT_LOW);
    k_msleep(1);

    err = adc_channel_setup_dt(&vbat_channel);
    if (!err) {
        err = adc_read(adc_dev, &seq);
    }

    gpio_pin_configure(gpio0_dev, VBAT_ENABLE_PIN, GPIO_DISCONNECTED);

    if (err) {
        return -1;
    }
    mv = raw;
    if (adc_raw_to_millivolts(adc_ref_internal(adc_dev),
                              vbat_channel.channel_cfg.gain, 12, &mv) < 0) {
        return -1;
    }
    return (int)(mv * DIVIDER_NUM / DIVIDER_DEN);
}

static void update_status_byte(void)
{
    int mv = battery_mv();
    int v;

    if (mv < 0) {
        return;
    }
    v = (mv - BATT_MV_MIN) * 63 / (BATT_MV_MAX - BATT_MV_MIN);
    if (v < 0) {
        v = 0;
    } else if (v > 63) {
        v = 63;
    }
    mfg_data[STATUS_IDX] = ((v & 0x38) << 2) | ((v & 0x07) << 1);
}

static void set_key(int idx, bt_addr_le_t *addr)
{
    const uint8_t *key = keys[idx];

    addr->type = BT_ADDR_LE_RANDOM;
    addr->a.val[0] = key[5];
    addr->a.val[1] = key[4];
    addr->a.val[2] = key[3];
    addr->a.val[3] = key[2];
    addr->a.val[4] = key[1];
    addr->a.val[5] = key[0] | 0xC0;

    mfg_data[0] = 0x4c;
    mfg_data[1] = 0x00;   /* Apple */
    mfg_data[2] = 0x12;
    mfg_data[3] = 0x19;   /* Find My / Offline Finding */
    /* mfg_data[4] is the battery status byte, managed separately */
    memcpy(&mfg_data[5], &key[6], 22);
    mfg_data[27] = (uint8_t)(key[0] >> 6);
    mfg_data[28] = 0x00;   /* hint */
}

int main(void)
{
    int err;

    bt_addr_le_t addr;
    int key_idx = 0;
    uint16_t progress = 0;
    int rot_id = -1;
    bool nvs_ok;
    int64_t base_ms = 0;

    pm_device_action_run(ext_flash_dev, PM_DEVICE_ACTION_SUSPEND);

    nvs_ok = (nvs_mount(&nvs) == 0);
    if (nvs_ok) {
        uint16_t v;

        if (nvs_read(&nvs, NVS_ID_PROGRESS, &v, sizeof(v)) == sizeof(v) &&
            v < PROGRESS_MAX) {
            progress = v;
        }
        key_idx = progress / CHUNKS_PER_ROT;
        base_ms = (int64_t)progress * CHUNK_MS;
    }

    set_key(key_idx, &addr);
    if (bt_id_create(&addr, NULL) < 0) {
        return 0;
    }

    err = bt_enable(NULL);
    if (err) {
        return 0;
    }

    mfg_data[STATUS_IDX] = STATUS_FIXED;
    update_status_byte();

    struct bt_le_adv_param adv_param = BT_LE_ADV_PARAM_INIT(
        BT_LE_ADV_OPT_USE_IDENTITY,
        1600,  // 1000 ms min
        3200,  // 2000ms max
        NULL
    );
    err = bt_le_adv_start(&adv_param, ad, ARRAY_SIZE(ad), NULL, 0);

    while (1) {
        k_sleep(K_MINUTES(1));

        int64_t elapsed = base_ms + k_uptime_get();
        uint16_t next_progress = (uint16_t)((elapsed / CHUNK_MS) % PROGRESS_MAX);
        int next = next_progress / CHUNKS_PER_ROT;

        if (next_progress != progress) {
            progress = next_progress;
            if (nvs_ok) {
                nvs_write(&nvs, NVS_ID_PROGRESS, &progress, sizeof(progress));
            }
        }

        if (next != key_idx) {
            int old_idx = key_idx;
            key_idx = next;
            bt_le_adv_stop();
            set_key(key_idx, &addr);
            bool id_ok = false;

            if (rot_id < 0) {
                int id = bt_id_create(&addr, NULL);

                if (id >= 0) {
                    rot_id = id;
                    adv_param.id = (uint8_t)id;
                    id_ok = true;
                }
            } else if (bt_id_reset(rot_id, &addr, NULL) >= 0) {
                adv_param.id = (uint8_t)rot_id;
                id_ok = true;
            }
            if (!id_ok) {
                key_idx = old_idx;
                set_key(old_idx, &addr);
            }

            update_status_byte();
            bt_le_adv_start(&adv_param, ad, ARRAY_SIZE(ad), NULL, 0);
        } else {
            update_status_byte();
            bt_le_adv_update_data(ad, ARRAY_SIZE(ad), NULL, 0);
        }
    }

    return 0;
}

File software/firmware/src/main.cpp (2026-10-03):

#include <Arduino.h>
#include <NimBLEDevice.h>

#define LED_PIN 10

uint8_t key[28] = { 0x1c, 0x4f, 0xe7, 0xea, 0x90, 0x86, 0xc2, 0x5d, 0xf7, 0x68, 0xb7, 0x9d, 0x57, 0x34, 0x5b, 0x5e, 0x52, 0xeb, 0xe6, 0xb7, 0xc4, 0xaf, 0xa4, 0x59, 0xb7, 0xdc, 0xe7, 0x10 };

void setup() {
    Serial.begin(9600);
    Serial.println("Starting...");

    pinMode(LED_PIN, OUTPUT);

    for (int b = 0; b < 2; b++) {
        digitalWrite(LED_PIN, HIGH);
        delay(100);
        digitalWrite(LED_PIN, LOW);
        delay(100);
    }
    delay(500);

    NimBLEDevice::init("");
    for (int b = 0; b < 3; b++) {
        digitalWrite(LED_PIN, HIGH);
        delay(100);
        digitalWrite(LED_PIN, LOW);
        delay(100);
    }
    Serial.println("NimBLE init OK");

    NimBLEDevice::setPower(ESP_PWR_LVL_N6);

    uint8_t addr[6] = {
        key[5], key[4], key[3], key[2], key[1],
        (uint8_t)(key[0] | 0xC0)
    };
    NimBLEDevice::setOwnAddrType(BLE_OWN_ADDR_RANDOM);
    ble_hs_id_set_rnd(addr);

    NimBLEAdvertisementData adv;
    std::string mfg;
    mfg.append("\x4c\x00", 2);
    mfg.append("\x12\x19", 2);
    mfg.append("\x00", 1);
    mfg.append((char *)&key[6], 22);
    mfg += (char)(key[0] >> 6);
    mfg.append("\x00", 1);
    adv.setManufacturerData(mfg);

    NimBLEAdvertising *a = NimBLEDevice::getAdvertising();
    a->setAdvertisementData(adv);
    a->setAdvertisementType(BLE_GAP_CONN_MODE_NON);
    bool started = a->start();

    Serial.printf("started=%d\n", started);
    for (int b = 0; b < 4; b++) {
        digitalWrite(LED_PIN, HIGH);
        delay(100);
        digitalWrite(LED_PIN, LOW);
        delay(100);
    }
}

void loop() {
    digitalWrite(LED_PIN, HIGH);
    delay(500);
    digitalWrite(LED_PIN, LOW);
    delay(500);
}

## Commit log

2026-06-05 lwk the schematic
    [hairtag.kicad_pcb, hairtag.kicad_sch]
2026-06-05 ditch ldo
    [hairtag.kicad_pcb, hairtag.kicad_sch]
2026-06-06 misc stuff
    [hairtag.kicad_pcb, hairtag.kicad_sch]
2026-06-06 readme stuff
    [hairtag.kicad_pcb, hairtag.kicad_sch]
2026-06-06 clean up tracks and vias
    [hairtag.kicad_pcb]
2026-06-06 whole assembly
2026-06-07 ungitignore csv files
    [BOM.csv, hairtag_1_bom.csv, hairtag_1_designators.csv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]
2026-06-10 refill I guess
    [hairtag.kicad_pcb]
2026-06-20 Bump cryptography in /firmware/esp32c3-openhaystack
    Bumps [cryptography](https://github.com/pyca/cryptography) from 48.0.0 to 48.0.1.
    - [Changelog](https://github.com/pyca/cryptography/blob/main/CHANGELOG.rst)
    - [Commits](https://github.com/pyca/cryptography/compare/48.0.0...48.0.1)
    ---
    updated-dependencies:
    - dependency-name: cryptography
    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
2026-06-29 add LED
    [hairtag.kicad_pcb, hairtag.kicad_sch, hairtag_1_bom.csv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]
2026-06-29 ordered it!
    [hairtag.kicad_pcb, hairtag.kicad_sch, hairtag_1_bom.csv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]
2026-07-18 OMG OMG OMG
    [hairtag.kicad_pcb, hairtag.kicad_sch]
2026-07-19 0.57 exportz
    [hairtag.kicad_pcb, hairtag_1_positions.csv]
2026-07-19 bom fix
    [hairtag.kicad_pcb, hairtag.kicad_sch]
2026-09-07 Revert "cadvertising"
    This reverts commit 180cbe4fb99a47468b9688e29276fcd08486fde8.
    [keygen.py, main.cpp]
2026-09-07 Reapply "cadvertising"
    This reverts commit 1ec73ddd48d9299d9acf9492b942f95bc495fdce.
    [keygen.py, main.cpp]
2026-09-08 Revert "weak"
    This reverts commit d8ee58b5f355fac44d422eec13db5066618d6515.
    [main.cpp]
2026-09-08 Revert "blink (works)"
    This reverts commit 519d62e11c7cbfcb13ea56f6b4c3127c65fa2b08.
    [main.cpp]
2026-09-19 [unflashed] cut bloat in code
2026-09-19 [untested] power-conscious konfig
2026-10-03 allegedly fix the race and prevent crashes
    [main.c]
2026-10-03 error handling and secret gen
    [keygen.py, main.c]
2026-10-03 findmy: add /raw.txt JSONL endpoint and Raw button
2026-10-03 findmy: /raw.txt JSONL endpoint, Raw button, use sys.executable for refresh subprocess
